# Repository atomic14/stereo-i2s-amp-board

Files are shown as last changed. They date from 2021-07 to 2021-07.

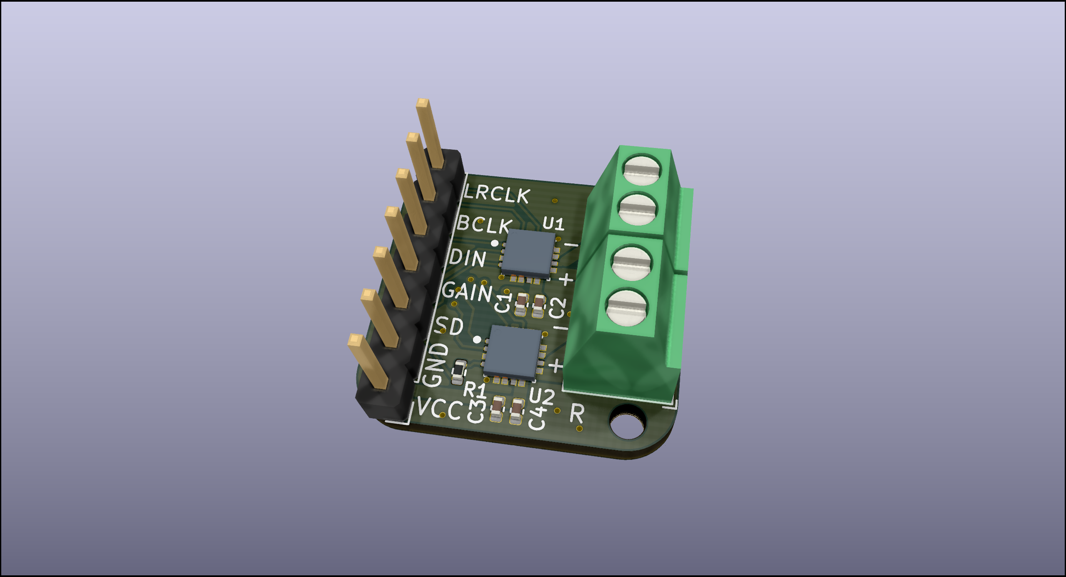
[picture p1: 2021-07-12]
StereoAmpV2.png

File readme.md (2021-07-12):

# MAX98357 Stereo Amplifier Breakout Board

Click the image below to watch a video on the design of this breakout board:

Demo Video (https://www.youtube.com/watch?v=RMPezTH0cck)

# Overview

This is a version of the Adafruit MAX98537 amplifier board, but with stereo output. It uses two MAX98357 ICs, one for the left channel and one for the right channel.

The board should be pretty much the same size as the Adafruit board, but the mounting holes are slightly smaller due to lack of space.

Pin out is the same, but you will have to take the SD line high to enable the output. Taking the SD line low will put the ICs into low power mode.

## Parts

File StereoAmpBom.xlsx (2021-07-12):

Item # | Designator | Quantity | Manufacturer | *Mfg Part # | Description / Value | *Package/Footprint | Instructions / Notes
1 | C1,C3 | 2 | PSA(Prosperity Dielectrics) | FS15B106M6R3PKG | 10uF ±20% 6.3V | C0402 | Any suitable replacement part is acceptable
2 | C2,C4 | 2 | Walsin Tech Corp | 0402X104K6R3CT | 100nF ±10% 6.3V | C0402 | Any suitable replacement part is acceptable
3 | R1 | 1 | UniOhm | 0402WGF2003TCE | 200kΩ ±1% 1/16W | R0402 | Any suitable 1% tolerance replacement part is acceptable
4 | U1,U2 | 2 | MAXIM(美信) | MAX98357AETE+T | MAX98357AETE+T | TQFN-16

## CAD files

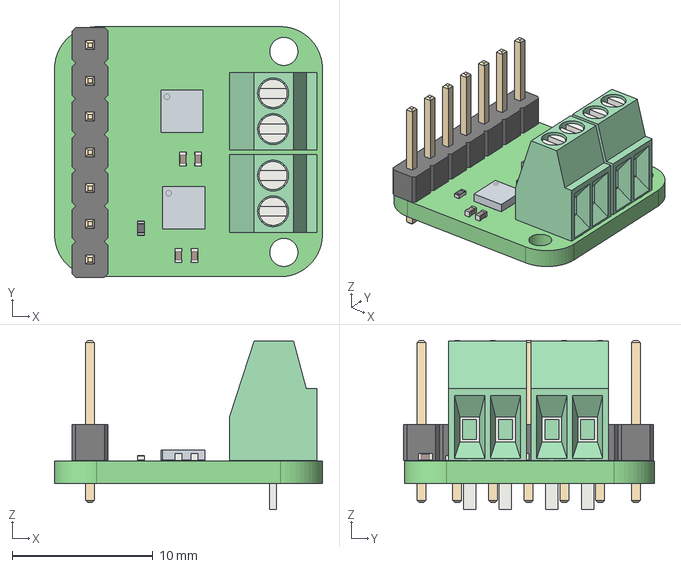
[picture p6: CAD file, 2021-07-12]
StereoAmpV2.step
19.1 x 17.8 x 12.0 mm

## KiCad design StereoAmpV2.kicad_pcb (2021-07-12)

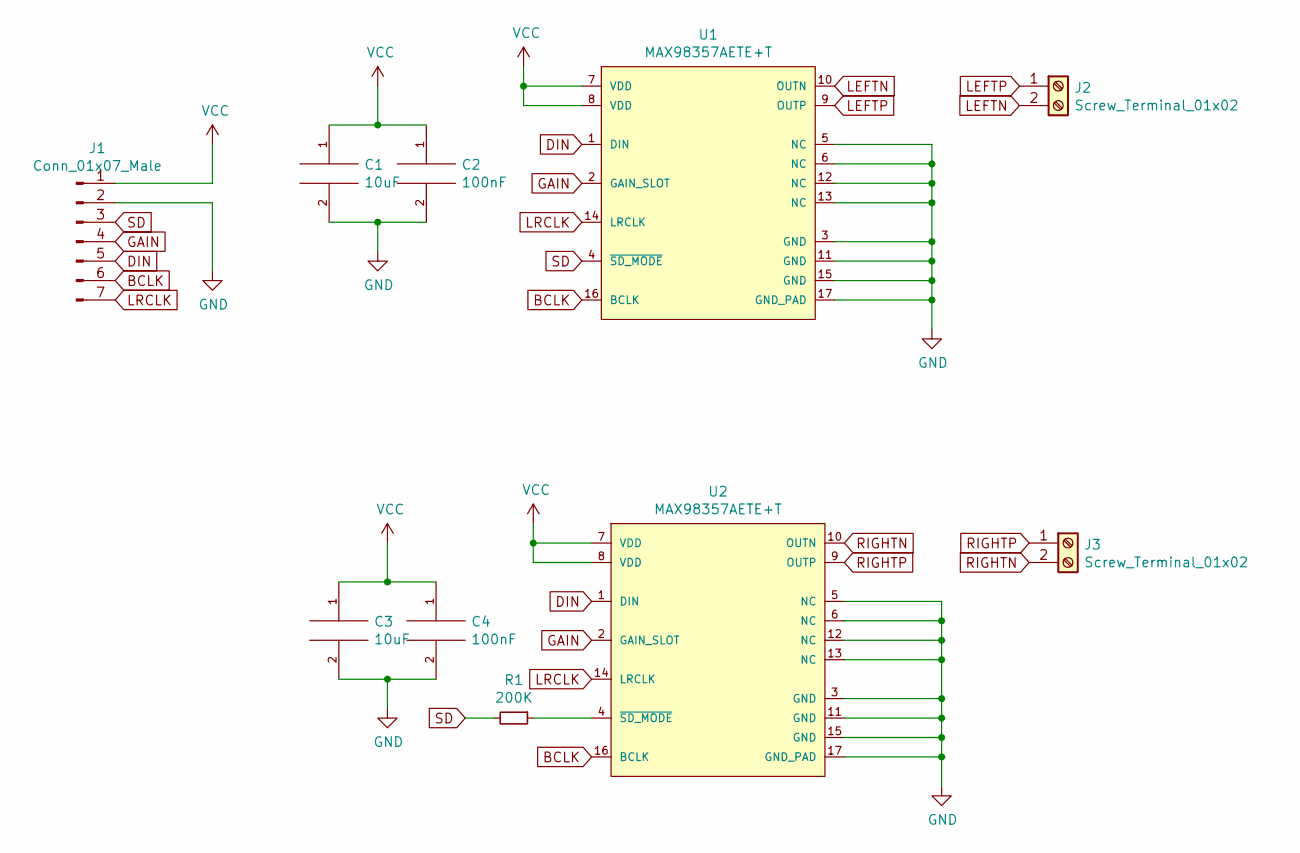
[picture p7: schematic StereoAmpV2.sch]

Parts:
C1, C3: 10uF; C_0402_1005Metric
C2, C4: 100nF; C_0402_1005Metric
J1: Conn_01x07_Male; PinHeader_1x07_P2.54mm_Vertical
J2, J3: Screw_Terminal_01x02; TerminalBlock_Phoenix_MPT-0,5-2-2.54_1x02_P2.54mm_Horizontal
R1: 200K; R_0402_1005Metric
U1, U2: MAX98357AETE+T; Maxim_Electronics-21-0896-0-0-0; mouser part number 700-MAX98357AETE+T; digikey description Amplifier IC 2-Channel (Stereo) Class D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

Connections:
BCLK: J1.6, U1.16 (BCLK), U2.16 (BCLK)
DIN: J1.5, U1.1 (DIN), U2.1 (DIN)
GAIN: J1.4, U1.2 (GAIN_SLOT), U2.2 (GAIN_SLOT)
GND: C1.2, C2.2, C3.2, C4.2, J1.2, U1.3 (GND), U1.5 (NC), U1.6 (NC), U1.11 (GND), U1.12 (NC), U1.13 (NC), U1.15 (GND), U1.17 (GND_PAD), U2.3 (GND), U2.5 (NC), U2.6 (NC), U2.11 (GND), U2.12 (NC), U2.13 (NC), U2.15 (GND), U2.17 (GND_PAD)
LEFTN: J2.2, U1.10 (OUTN)
LEFTP: J2.1, U1.9 (OUTP)
LRCLK: J1.7, U1.14 (LRCLK), U2.14 (LRCLK)
unnamed: R1.1, U2.4 (~SD_MODE~)
RIGHTN: J3.2, U2.10 (OUTN)
RIGHTP: J3.1, U2.9 (OUTP)
SD: J1.3, R1.2, U1.4 (~SD_MODE~)
VCC: C1.1, C2.1, C3.1, C4.1, J1.1, U1.7 (VDD), U1.8 (VDD), U2.7 (VDD), U2.8 (VDD)

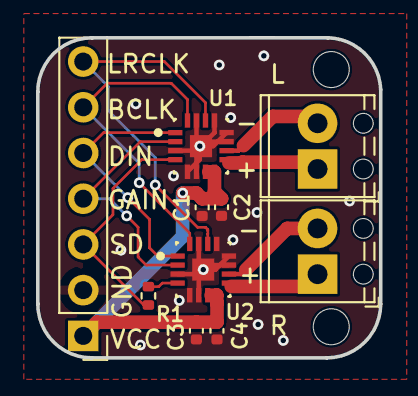
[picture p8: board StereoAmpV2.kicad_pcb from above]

Board: 2 copper layers, 19.1 x 17.8 mm, 10 parts (0 on the bottom side), 12 nets.
